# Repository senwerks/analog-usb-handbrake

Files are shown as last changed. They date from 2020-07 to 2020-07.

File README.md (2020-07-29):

# Analog USB Handbrake for Racing Sims

A conversion kit to turn any real car handbrake (eg cheap drift/race handbrakes from eBay/Amazon) into an analog USB handbrake for racing sims.

## Required

- Cheap drift/race handbrake such as [this one](https://www.amazon.com.au/Kyostar-Universal-Hydraulic-Handbrake-Parking/dp/B07WPS87Y3/) (similar are available from all major online marketplaces)
- Spring/shock from a 1:10 RC car such as [this one](https://www.amazon.com.au/HobbyPark-Aluminum-Absorber-Brontosaurus-Replacement/dp/B01A0ZB95Y/).
- Arduino Pro Micro / Leonardo
- 10k sliding potentiometer
- Zip ties
- 3D printer

## Instructions

Attach [Potentiometer Bracket](https://github.com/obsoletenerd/analog-usb-handbrake/blob/master/Potentiometer-Bracket.stl) to the front of the potentiometer.

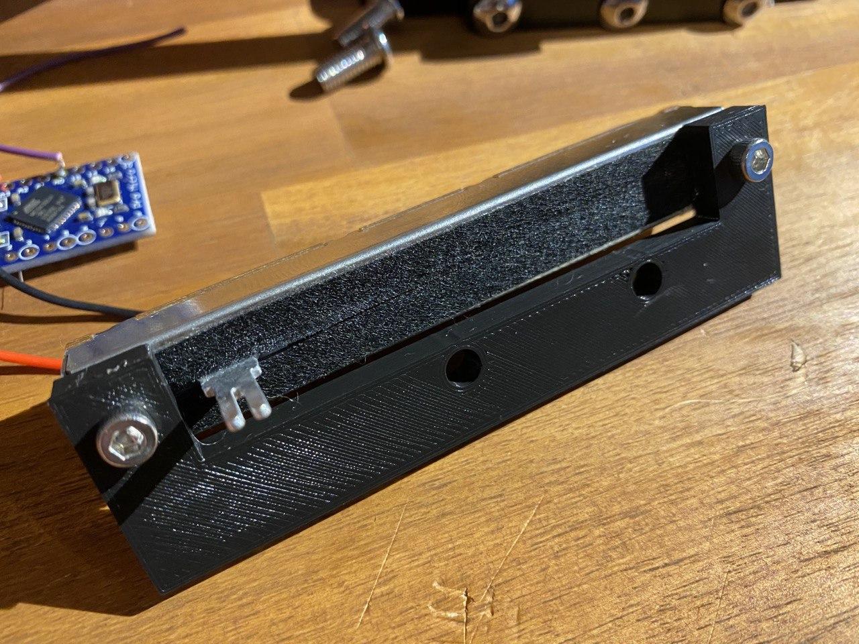
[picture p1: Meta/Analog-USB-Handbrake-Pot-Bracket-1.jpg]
Potentiometer Bracket


Strip the handbrake of all non-required parts. You just need the handbrake lever itself and the supporting frame.

Screw the sliding pot bracket to the inside edge of the handbrake frame/chassis, using some of the leftover bolts from stripping the handbrake (I found I had more than enough). 

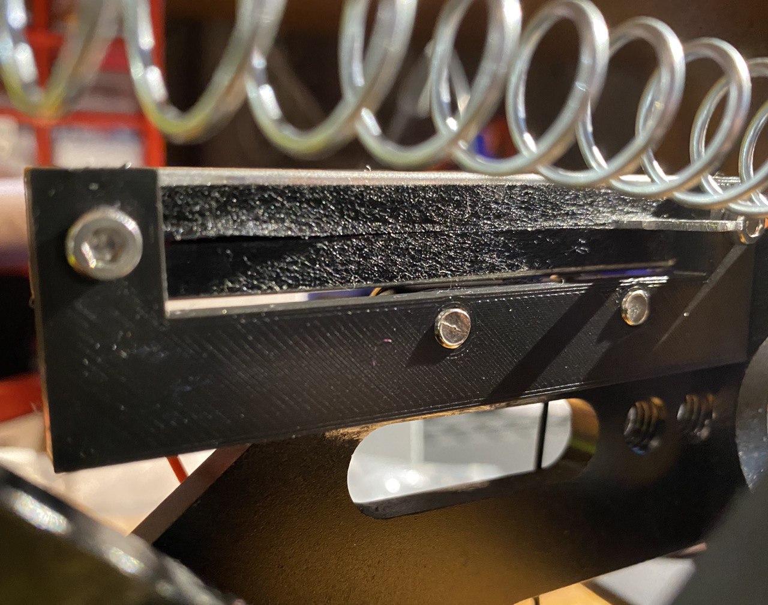
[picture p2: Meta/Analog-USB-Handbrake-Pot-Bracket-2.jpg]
Potentiometer Bracket


Print the [Shock Mount](https://github.com/obsoletenerd/analog-usb-handbrake/blob/master/Rear-Shock-Mount.stl) and use another of the spare screws to attach it to the rear mount point, and zip-tie the other end to the handbrake shaft (I've clocked many hours on this setup now and the zip-tie has held fine).

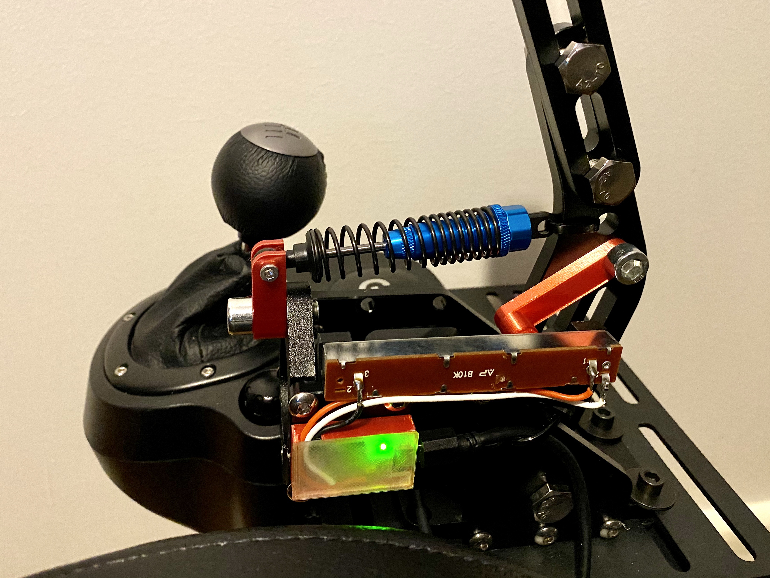
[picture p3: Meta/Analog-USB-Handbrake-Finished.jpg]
Finished Analog USB Handbrake


Clip the [Connecting Arm](https://github.com/obsoletenerd/analog-usb-handbrake/blob/master/Connecting-Arm.stl) to the potentiometer slider and then put a bolt through the other end to attach it to the handbrake lever itself. Ignore the spring, that was an earlier prototype, and if you can't get an RC shock, actually worked surprisingly well considering it's a cheap Gate spring from the hardware shop.

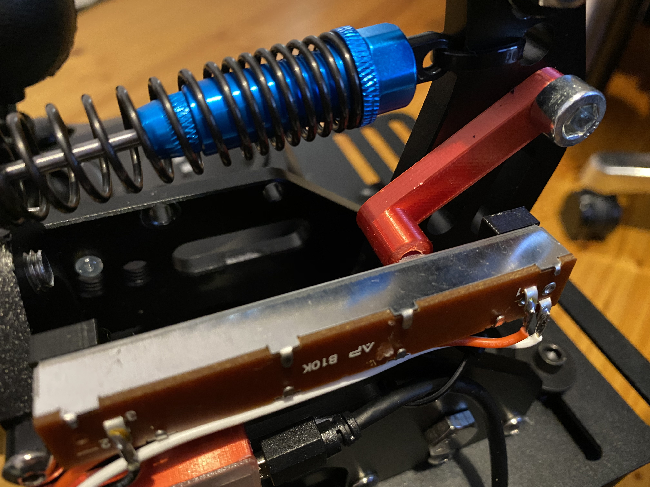
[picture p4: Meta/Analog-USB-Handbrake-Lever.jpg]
Handbrake Lever Attached


Flash [the Arduino code](https://github.com/obsoletenerd/analog-usb-handbrake/blob/master/Arduino-Analog-USB-Handbrake/Arduino-Analog-USB-Handbrake.ino) onto the Arduino Leonardo/Pro Micro, and connect the wiring (Pot pin 1 to VCC, pot pin 2 to A0, and pot pin 3 to GND).

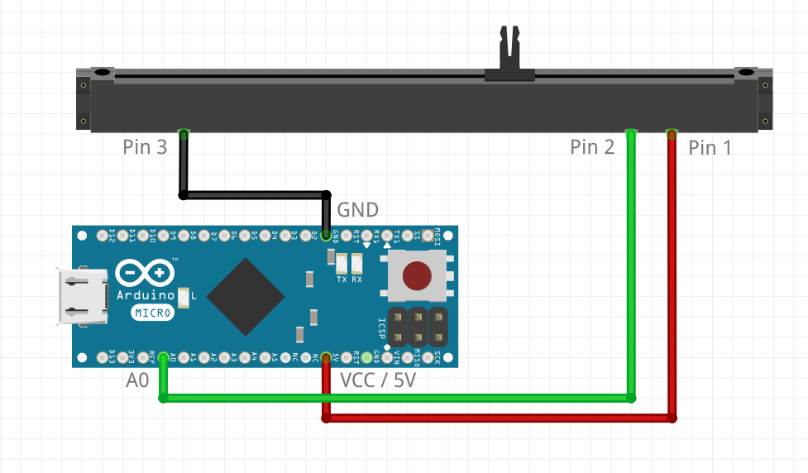
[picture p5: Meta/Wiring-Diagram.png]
Wiring Diagram


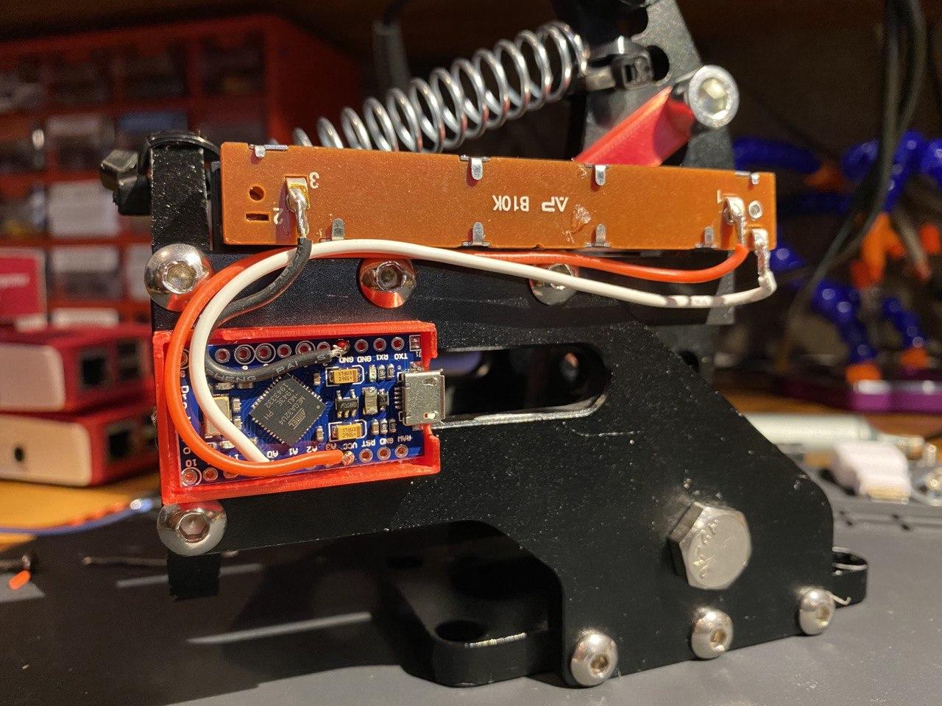
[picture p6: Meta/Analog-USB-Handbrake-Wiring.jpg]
Wiring Photo


Place the Arduino into the [Arduino Case](https://github.com/obsoletenerd/analog-usb-handbrake/blob/master/Arduino-Case.stl) to insulate the back of the Arduino from touching the metal handbrake parts, and hot glue it into place, and optionally cover it with the 3D printed [Arduino Lid](https://github.com/obsoletenerd/analog-usb-handbrake/blob/master/Arduino-Case.stl) (I did clear, so I can see the LEDs still).

Go get sideways!

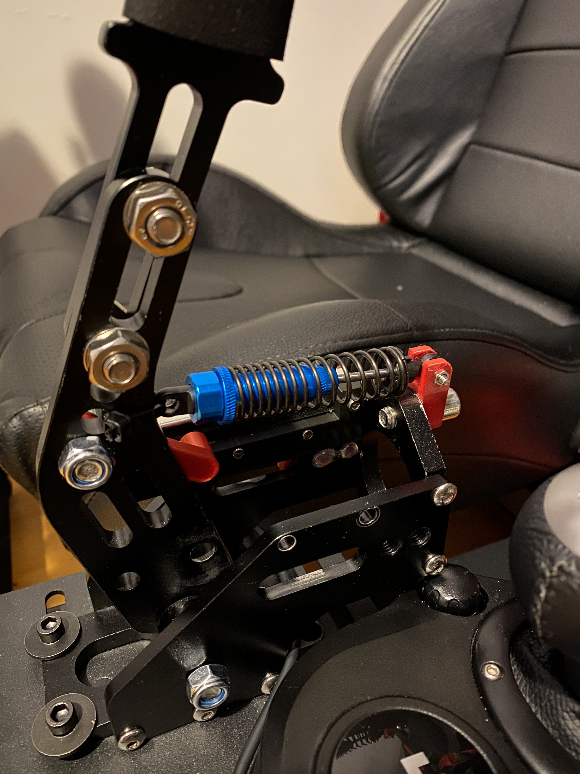
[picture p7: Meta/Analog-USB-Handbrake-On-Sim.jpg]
Analog USB Handbrake on the Sim


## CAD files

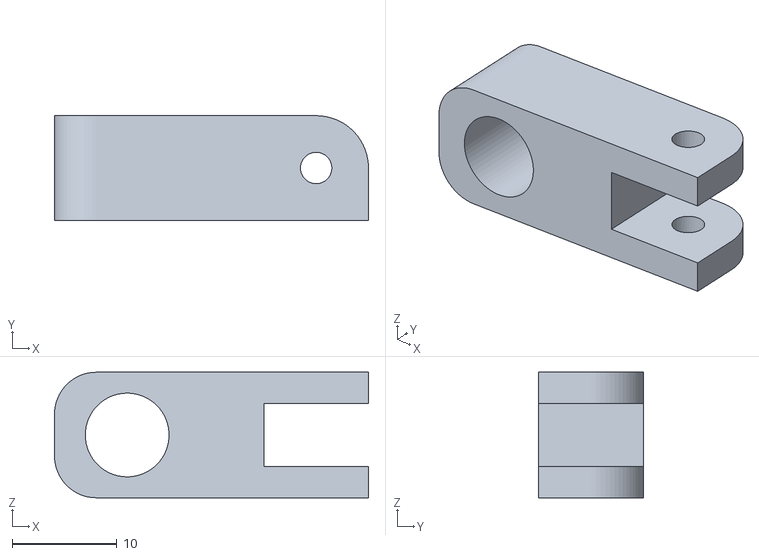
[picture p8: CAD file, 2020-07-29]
Rear-Shock-Mount.stl
30.0 x 10.0 x 12.0

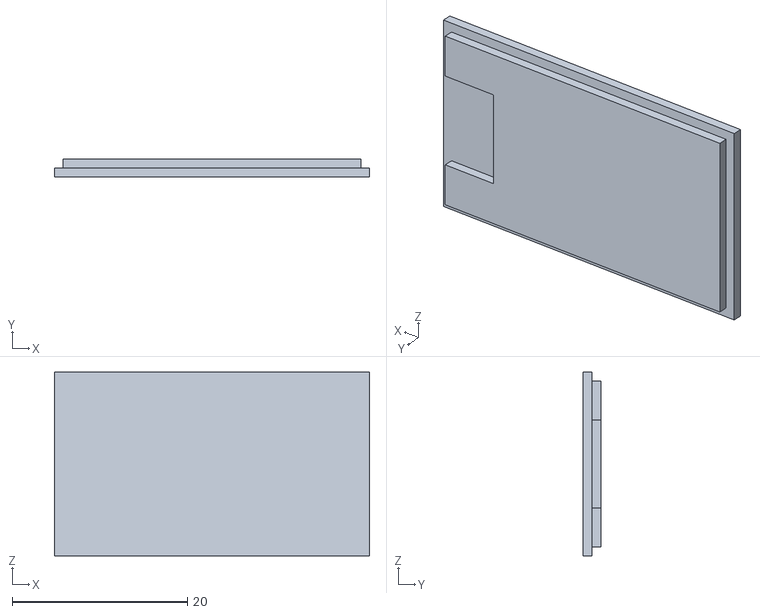
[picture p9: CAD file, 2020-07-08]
Arduino-Lid.stl
36.0 x 2.00 x 21.0

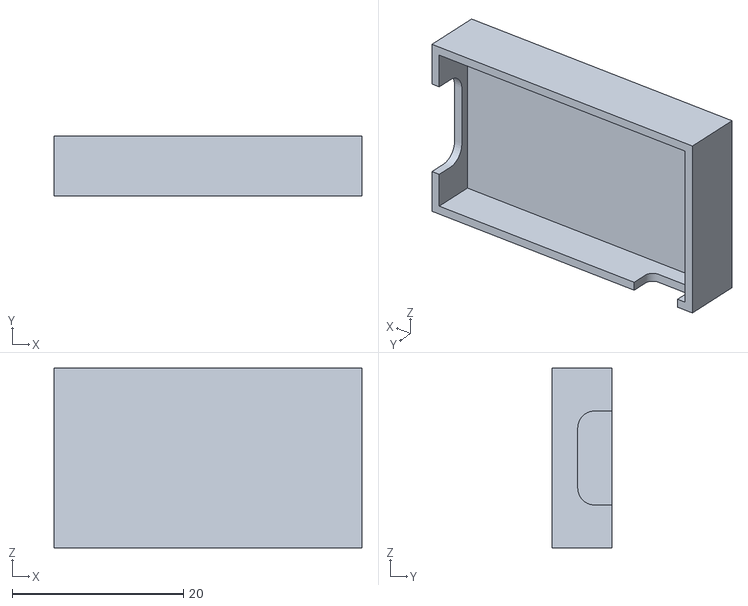
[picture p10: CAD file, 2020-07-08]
Arduino-Case.stl
36.0 x 7.00 x 21.0

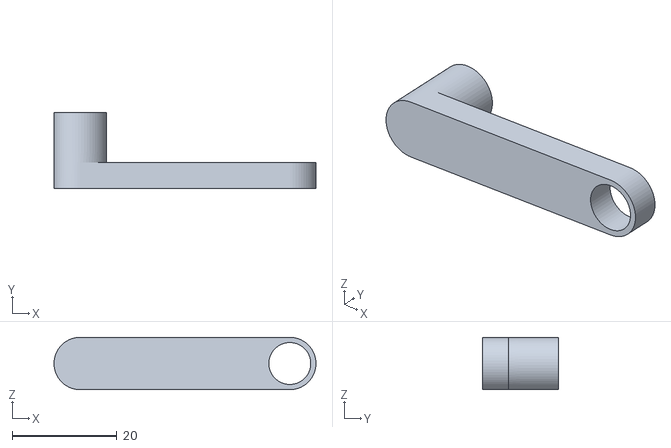
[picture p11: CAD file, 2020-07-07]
Connecting-Arm.stl
50.0 x 14.5 x 10.0

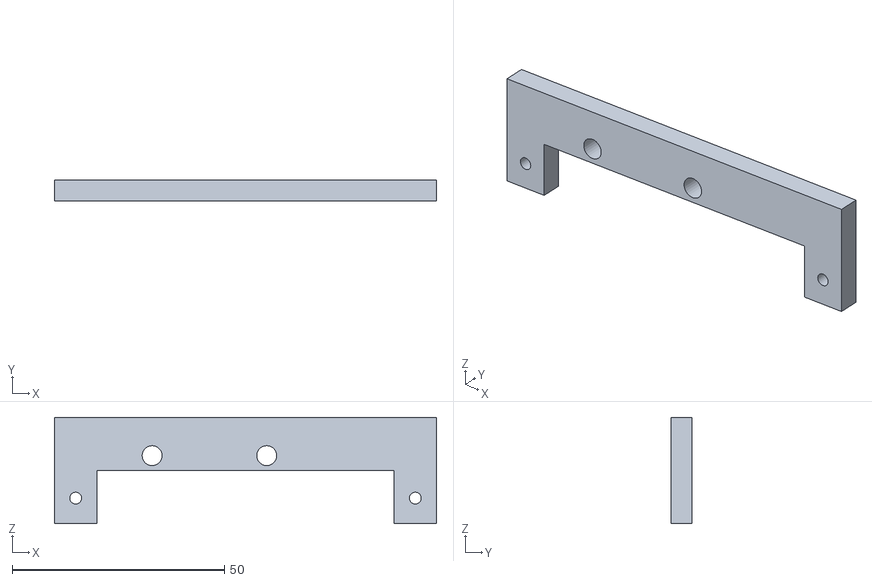
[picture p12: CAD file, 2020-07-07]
Potentiometer-Bracket.stl
90.0 x 5.00 x 25.0

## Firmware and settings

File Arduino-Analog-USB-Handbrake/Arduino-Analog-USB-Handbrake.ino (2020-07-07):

/*
 * USB Analog Handbrake by @obsoletenerd
 * http://github.com/obsoletenerd/analog-usb-handbrake
 * 
 * Pot pin 1 to VCC
 * Pot pin 2 to A0
 * Pot pin 3 to GND
 */
#include <Joystick.h>
const int potPin = A0; // Change if using a different pin

void setup() {
  Serial.begin(9600);
  pinMode(potPin, INPUT);
  Joystick.begin();
}

void loop() {
  int potReading = analogRead(potPin);
  Serial.println("Pot: ");
  Serial.print(potReading);
  int mappedReading = map(potReading,0,1023,0,255);
  Serial.println("Mapped: ");
  Serial.print(mappedReading);
  Joystick.setThrottle(mappedReading);
}

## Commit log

2020-07-07 Typos in README
    [Arduino-Case.stl, Connecting-Arm.stl, Potentiometer -racket.stl]
2020-07-07 I'm too tired for this crap
    [Potentiometer-Bracket.stl]
2020-07-08 Tidied it all up
    [Arduino-Case.stl, Arduino-Lid.stl]
2020-07-29 Updated photos and README to suit new parts
    [Rear-Shock-Mount.stl]
